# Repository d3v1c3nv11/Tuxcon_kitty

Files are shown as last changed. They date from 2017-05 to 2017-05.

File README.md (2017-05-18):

# DIY: Tuxcon_kitty

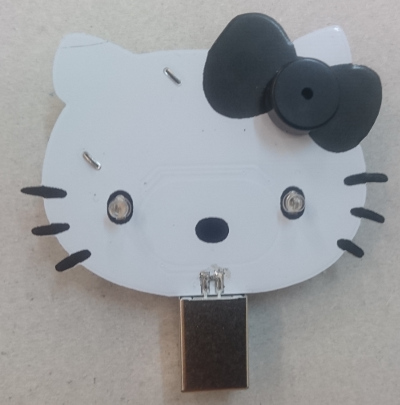
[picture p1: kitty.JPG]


Olimex's Tuxcon kitty

Arduino sketch file: https://github.com/d3v1c3nv11/Tuxcon_kitty/tree/master/hello_kitty

Hardware: https://github.com/d3v1c3nv11/Tuxcon_kitty/tree/master/Tuxcon_Kitty_hardware

Schematic in pdf format: https://github.com/d3v1c3nv11/Tuxcon_kitty/blob/master/tuxcon_kitty.pdf

################## IMPORTANT NOTE ##################

 Tuxcon Kitty board is preprogramed with modified micronucleus-t85 bootloader. You can download from here: https://github.com/d3v1c3nv11/micronucleus-t85

################## ENJOY! ##################

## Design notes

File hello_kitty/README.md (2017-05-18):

To upload the Arduino sketch file, you must:

################## Add the Attiny85 board support in Arduino ##################

1. Launch Arduino.
2. Go to:  File->Preferences
3. In the field "Additional Boards Managers URLs", add these links:
http://digistump.com/package_digistump_index.json
https://raw.githubusercontent.com/damellis/attiny/ide-1.6.x-boards-manager/package_damellis_attiny_index.json
4. Click "OK" to save changes

################## Add Micronucleus Programmer to Arduino IDE ##################

Please visit this web page to see how to add Micronucleus support to Arduino IDE
http://www.instructables.com/id/Adding-Digispark-with-bootloader-support-to-existi/

################## BEFOR UPLOADING THE SKETCH ##################

In order to compile and upload this program, you must have installed "Capacitive Sensor" library.
You can download it from:
http://playground.arduino.cc/Main/CapacitiveSensor?from=Main.CapSense

################## Compile and Download ##################

Before Compilation and Upload, you MUST UNPLUG your USB cable from this board.
Then you must choose the right board. To do so:

1. Go to  "Tools" menu and then to "Board:" submenu.
2. Scroll down until you find "Digispark (8mhz - No USB) "
3. Select that board.
4. Click Upload
5. In the black box in Arduino IDE (the output of Compiling/Uploading) you will see message like:
" Running Digispark Uploader...
  Plug in device now... (will timeout in 60 seconds) "
5. Plug-in the USB cable to the board.
6. Then you should see message in the same box, that says the Uploading is completed.

################## IMPORTANT NOTE ##################

This sketchfile is written to work with external DC supply (CR2032 battery), so if you want to 
power your Kitty board with USB, instead of battery, you should change this line from the sketch file:

 if (capacitance > 8)
Should be changed to:

 if (capacitance > 30) // If that value is incorrect, try changing it with different values, untill you manage to
start the Kitty singing by touching it's nose.

################## ENJOY! ##################

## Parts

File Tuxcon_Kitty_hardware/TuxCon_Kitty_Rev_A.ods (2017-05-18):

Designation | Quantity | Designator | Package
BADGE-PIN-CLIPS | 1
СЪЕДИНИТЕЛ USB-SDWH-4B-LF (USB-B ПРАВ) | 1 | USB1 | USB-B-EDGE
SMD ИС ATTINY85-20SU | 1 | U1 | SO-8_208mil
LED 3mm PTH BLUE | 2 | LED2,LED1 | LED-3mm-PTH-KA
БАТЕРИЯ Li 3 V 220 mAh CR2032-V | 1 | BAT1 | CR2032H
CR2032H_PTH | 1 | BAT1 | CR2032H_PTH
BUZZER PT1240P 20Vpp 4kHz 13.8MM | 1 | BUZ1 | BUZZER-PT1240
SMD КОНД 1206 12 PF C0G 50VDC 5% | 1 | C1 | C_1206_5MIL_DWS
SMD КОНД 1206 1 UF Y5V 50VDC 20% | 1 | C2 | C_1206_5MIL_DWS
SMD ДИОД MINIMELF LL1N4148 | 2 | D2,D3 | SOD80C-4148-KA
SMD ДИОД 1N5819 (S4) SOD-123 | 1 | D1 | SOD80C-4148-KA
SMD РЕЗ 1206 1 K 5% | 2 | R1,R2 | R_1206_5MIL_DWS
SMD РЕЗ 1206 1 M 5% | 2 | R3,R4 | R_1206_5MIL_DWS
SMD РЕЗ 1206 10 K 5% | 1 | R5 | R_1206_5MIL_DWS
SMD РЕЗ 1206 22 OHM 5% | 2 | R6,R7 | R_1206_5MIL_DWS
SMD РЕЗ 0805 1.5 K 5% | 1 | R8 | R_0805_5MIL_DWS
BATTERY CR2032H | 1
ГПП – Tuxcon Kitty_Rev.A | 1

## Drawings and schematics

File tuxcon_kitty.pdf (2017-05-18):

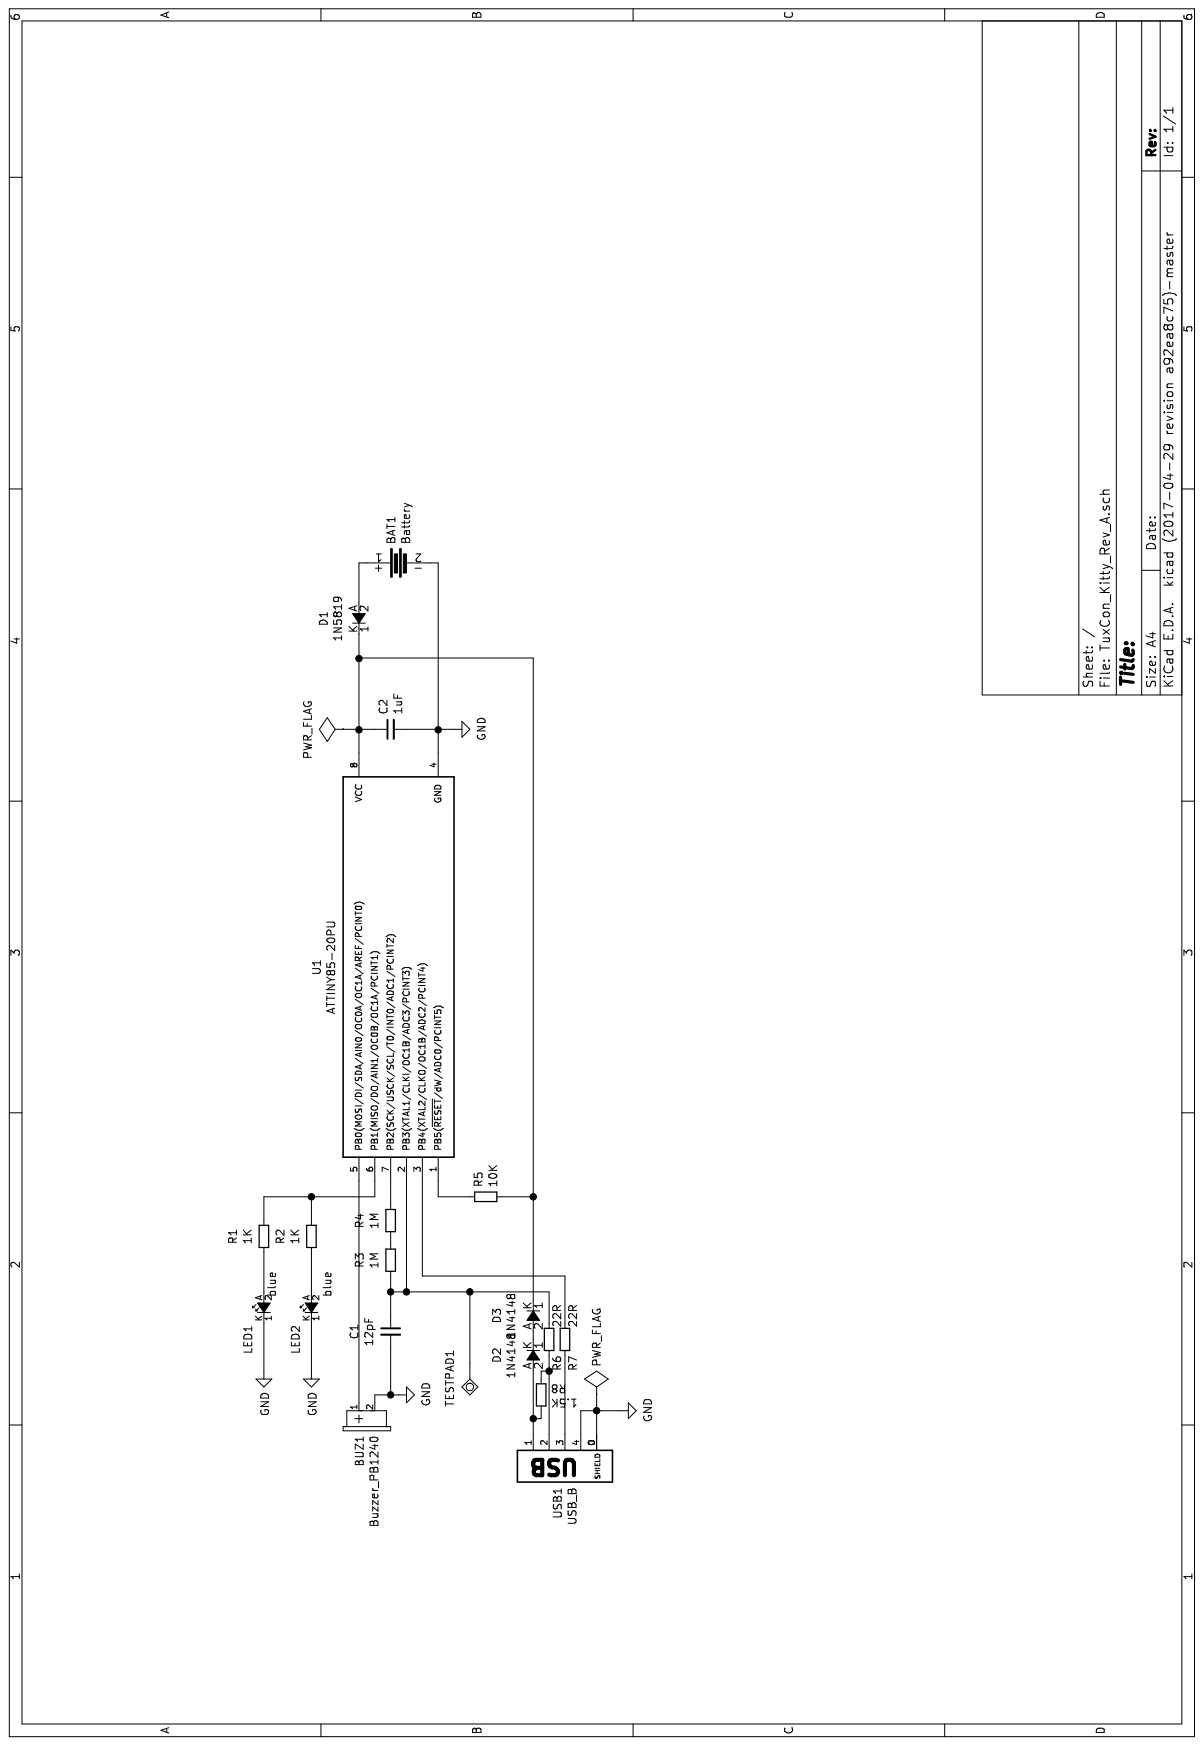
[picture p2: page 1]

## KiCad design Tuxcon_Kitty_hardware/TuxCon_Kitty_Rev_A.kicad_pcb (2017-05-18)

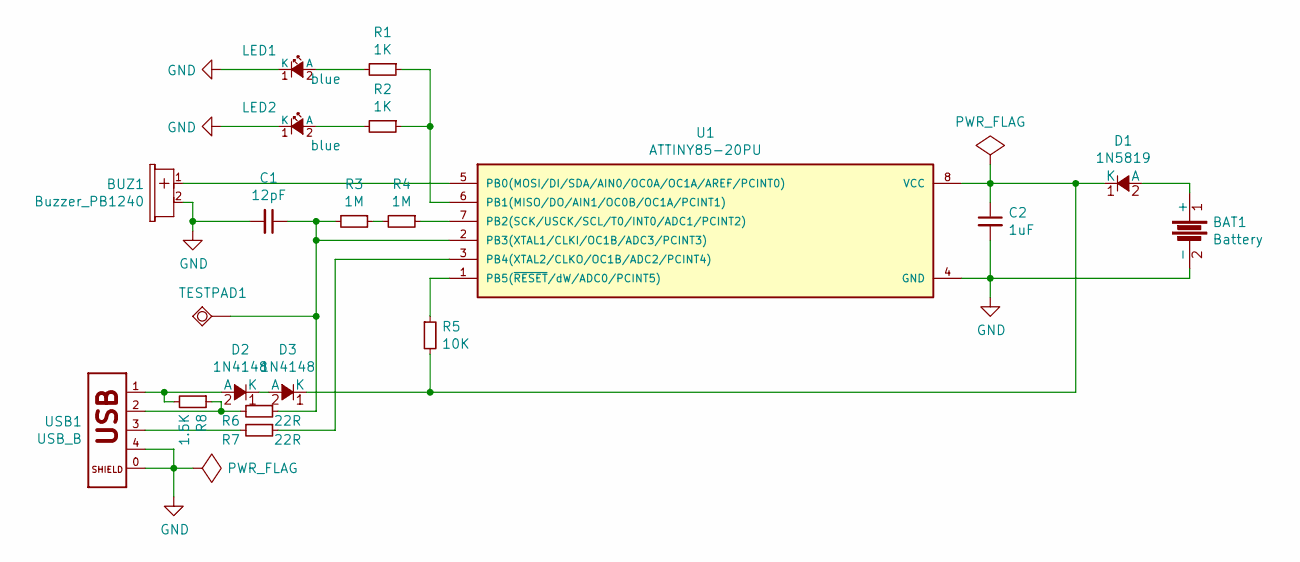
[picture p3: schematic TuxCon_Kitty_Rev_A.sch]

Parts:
BAT1: Battery; CR2032H_PTH
BUZ1: Buzzer_PB1240; BUZZER-PB1240
C1: 12pF; C_1206_5MIL_DWS
C2: 1uF; C_1206_5MIL_DWS
D1: 1N5819; SOD80C-4148-KA
D2, D3: 1N4148; SOD80C-4148-KA
LED1, LED2: blue; LED-3mm-PTH-KA
R1, R2: 1K; R_1206_5MIL_DWS
R3, R4: 1M; R_1206_5MIL_DWS
R5: 10K; R_1206_5MIL_DWS
R6, R7: 22R; R_1206_5MIL_DWS
R8: 1.5K; R_1206_5MIL_DWS
TESTPAD1: TESTPAD; TP_SMD_10.00x8.00mm
U1: ATTINY85-20PU; SOIC-8
USB1: USB_B; USB_Mini-B

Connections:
GND: BAT1.2 (-), BUZ1.2 (MINUS), C1.2, C2.2, LED1.1 (K), LED2.1 (K), U1.4 (GND), USB1.0 (5), USB1.4
unnamed: BAT1.1 (+), D1.2 (A)
unnamed: BUZ1.1 (PLUS), U1.5 (PB0(MOSI/DI/SDA/AIN0/OC0A/OC1A/AREF/PCI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)
unnamed: C1.1, R3.2, R6.1, TESTPAD1.1, U1.2 (PB3(XTAL1/CLKI/OC1B/ADC3/PCINT3))
unnamed: C2.1, D1.1 (K), D3.1 (K), R5.2, U1.8 (VCC)
unnamed: D2.1 (K), D3.2 (A)
unnamed: D2.2 (A), R8.2, USB1.1
unnamed: LED1.2 (A), R1.2
unnamed: LED2.2 (A), R2.2
unnamed: R1.1, R2.1, U1.6 (PB1(MISO/DO/AIN1/OC0B/OC1A/PCINT1))
unnamed: R3.1, R4.2
unnamed: R4.1, U1.7 (PB2(SCK/USCK/SCL/T0/INT0/ADC1/PCINT2))
unnamed: R5.1, U1.1 (PB5(~RESET~/dW/ADC0/PCINT5))
unnamed: R6.2, R8.1, USB1.2
unnamed: R7.1, U1.3 (PB4(XTAL2/CLKO/OC1B/ADC2/PCINT4))
unnamed: R7.2, USB1.3

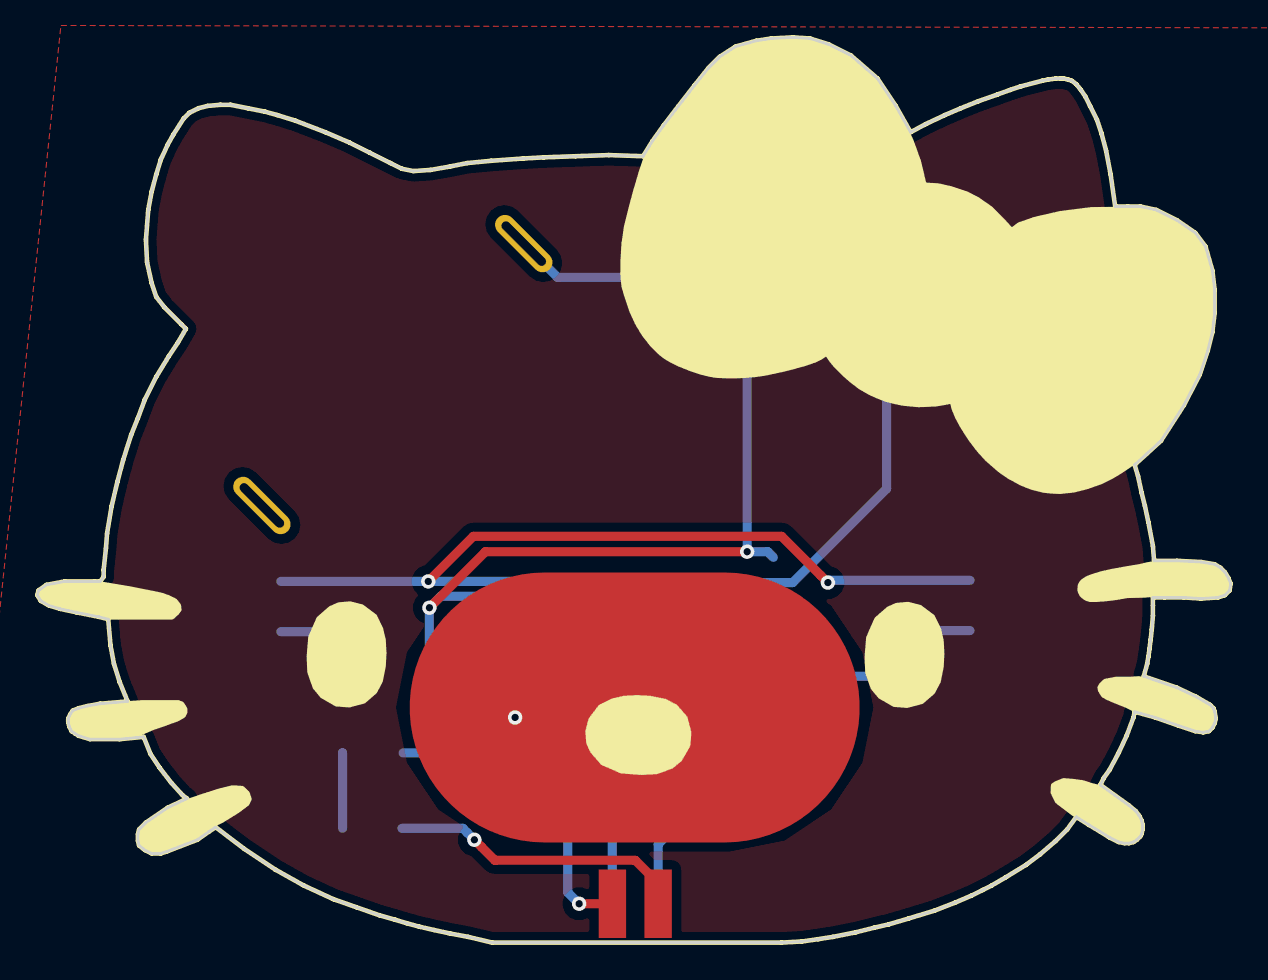
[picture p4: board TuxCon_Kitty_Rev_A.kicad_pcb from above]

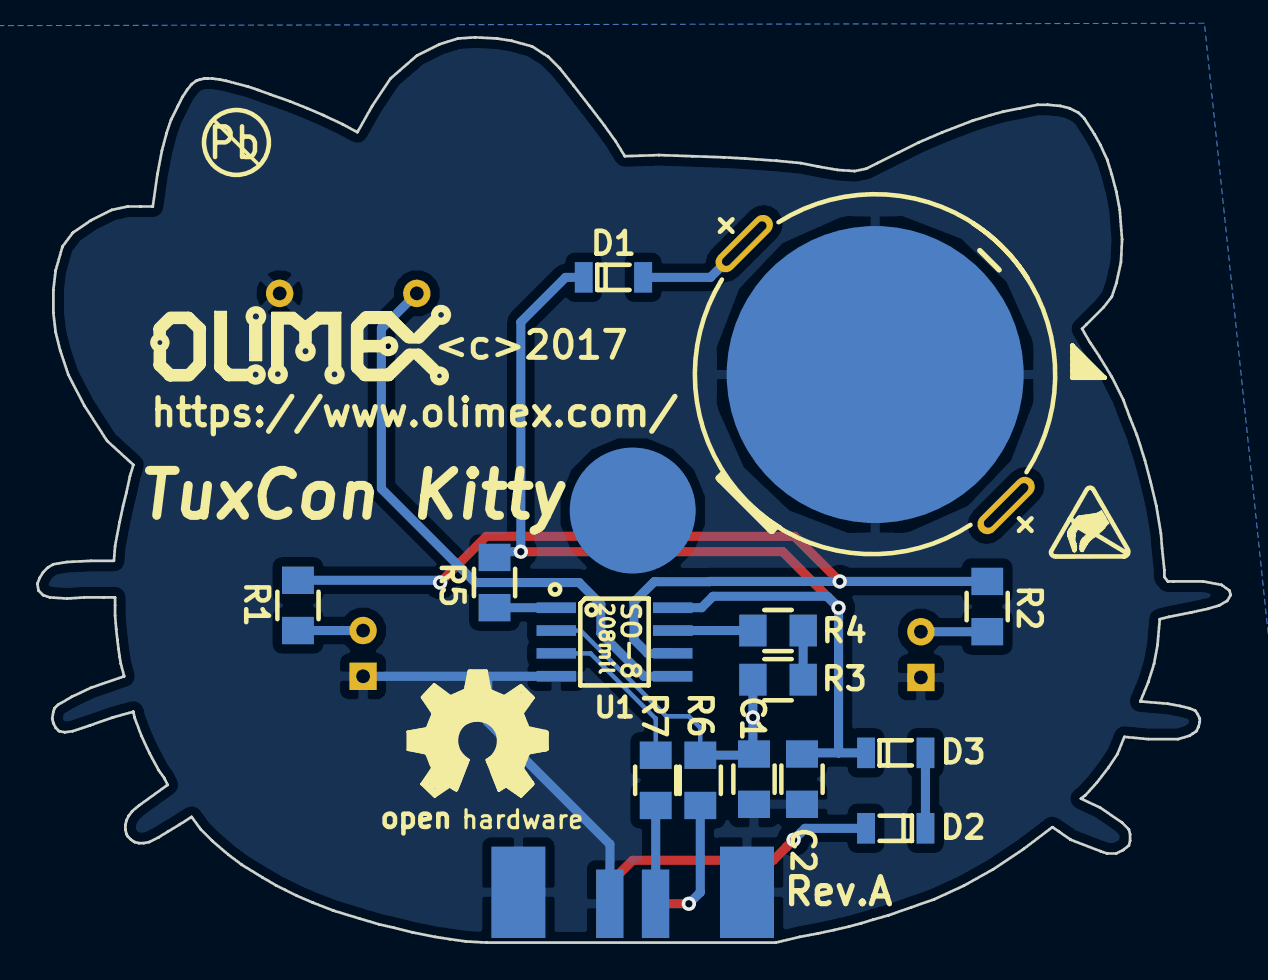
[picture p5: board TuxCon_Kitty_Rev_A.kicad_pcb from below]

Board: 2 copper layers, 66.3 x 50.3 mm, 21 parts (16 on the bottom side), 16 nets.

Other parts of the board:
Ref**: Val**; LOGO_ANTISTATIC_SMALL_4.5mmX2.8mm
TESTPAD1#2: TESTPAD; TP_SMD_10.00x8.00mm

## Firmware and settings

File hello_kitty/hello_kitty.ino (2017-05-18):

#include <avr/pgmspace.h>
#include <avr/io.h>
#include <avr/wdt.h>
#include <avr/sleep.h>
#include <avr/interrupt.h>
#include <CapacitiveSensor.h>
#include "definedtones.h"

//DefinePinNumebers:
int buzzer = 0;
int led = 1;
int chrge = 2;
int dischrge = 3;

CapacitiveSensor cs_2_3 = CapacitiveSensor(2, 3);


const int song[] PROGMEM = {
  G3,
  A3,
  DS3,
  E3,
  D3,
  DS3,
  D3,
  C3,
  C3,
  D3,
  DS3,
  DS3,
  D3,
  C3,
  D3,
  E3,
  G3,
  A3,
  E3,
  G3,
  D3,
  E3,
  C3,
  D3,
  C3,
  E3,
  G3,
  A3,
  E3,
  G3,
  C3,
  D3,
  C3,
  DS3,
  E3,
  DS3,
  D3,
  C3,
  D3,
  DS3,
  DS3,
  D3,
  C3,
  D3,
  E3,
  G3,
  D3,
  C3,
  D3,
  C3,
  C3,
  C3,
  G2,
  A2,
  C3,
  G2,
  A2,
  C3,
  E3,
  F3,
  E3,
  F3,
  E3,
  F3,
  G3,
  C3,
  C3,
  G2,
  A2,
  C3,
  E3,
  F3,
  E3,
  F3,
  G3,
  C3,
  B2,
  C3,
  G2,
  A2,
  C3,
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
};
const int duration[] PROGMEM = {
  QTH,
  QTH,
  ETH,
  QTH,
  ETH,
  ETH,
  ETH,
  QTH,
  QTH,
  QTH,
  QTH,
  ETH,
  ETH,
  ETH,
  ETH,
  ETH,
  ETH,
  ETH,
  ETH,
  ETH,
  ETH,
  ETH,
  ETH,
  ETH,
  ETH,
  QTH,
  QTH,
  ETH,
  ETH,
  ETH,
  ETH,
  ETH,
  ETH,
  ETH,
  ETH,
  ETH,
  ETH,
  ETH,
  ETH,
  QTH,
  ETH,
  ETH,
  ETH,
  ETH,
  ETH,
  ETH,
  ETH,
  ETH,
  QTH,
  QTH,
  QTH,
  QTH,
  ETH,
  ETH,
  QTH,
  ETH,
  ETH,
  ETH,
  ETH,
  ETH,
  ETH,
  ETH,
  ETH,
  ETH,
  ETH,
  QTH,
  QTH,
  ETH,
  ETH,
  ETH,
  ETH,
  ETH,
  ETH,
  ETH,
  ETH,
  QTH,
  QTH,
  QTH,
  ETH,
  ETH,
  QTH,
  ETH,
  ETH,
  ETH,
  ETH,
  ETH,
  ETH,
  ETH,
  ETH,
  ETH,
  ETH,
  QTH,
  QTH,
  ETH,
  ETH,
  ETH,
  ETH,
  ETH,
  ETH,
  QTH,
  HTH,

};

void setup_watchdog(int timerPrescaler) {

  if (timerPrescaler > 9 ) timerPrescaler = 9; //Correct incoming amount if need be

  byte bb = timerPrescaler & 7;
  if (timerPrescaler > 7) bb |= (1 << 5); //Set the special 5th bit if necessary

  //This order of commands is important and cannot be combined
  MCUSR &= ~(1 << WDRF); //Clear the watch dog reset
  WDTCR |= (1 << WDCE) | (1 << WDE); //Set WD_change enable, set WD enable
  WDTCR = bb; //Set new watchdog timeout value
  WDTCR |= _BV(WDIE); //Set the interrupt enable, this will keep unit from resetting after each int
}

ISR(WDT_vect) {

}

void enterSleep(void)
{
  set_sleep_mode(SLEEP_MODE_PWR_DOWN);   /* EDIT: could also use SLEEP_MODE_PWR_DOWN for lowest power consumption. */
  sleep_enable();

  /* Now enter sleep mode. */
  sleep_mode();

  /* The program will continue from here after the WDT timeout*/
  sleep_disable(); /* First thing to do is disable sleep. */

  /* Re-enable the peripherals. */
  // power_all_enable();
}

void setup() {

  pinMode(led, OUTPUT);
  digitalWrite(led, LOW);
  pinMode(buzzer, OUTPUT);
  digitalWrite(buzzer, LOW);


  cs_2_3.set_CS_AutocaL_Millis(0xFFFFFFFF);
  //Serial.begin(115200);

  set_sleep_mode(SLEEP_MODE_PWR_DOWN);
  sleep_enable();
  ADCSRA &= ~(1 << ADEN); //Disable ADC, saves ~230uA
  setup_watchdog(7); //Wake up after 2s.
}



void loop() {
  int cnote = 0;
  int cdur = 0;
  int ddelay = 0;
  bool ledon = 0;

  long i = 0;
  int temp = 0;

  long capacitance = 0;

  /*
  pinMode(2, OUTPUT);
  pinMode(3, INPUT);
  digitalWrite(2, LOW);
  while (digitalRead(3));

  pinMode(3, OUTPUT);
  pinMode(2, INPUT);
  digitalWrite(3, HIGH);
  while (!digitalRead(2)) i++;
  */

  
  //i = mycap.capacitiveSensor(30);


  //digitalWrite(1,HIGH);
  capacitance = cs_2_3.capacitiveSensor(30);

  if (capacitance > 8)
  {
    //for(int cnt=0;cnt<133;cnt++)
    for (int cnt = 0; cnt < 101; cnt++)
    {
      if (!ledon)  {
        digitalWrite(led, LOW);
        ledon = 1;
      }
      else
      {
        digitalWrite(led, HIGH);
        ledon = 0;
      }
      cnote = pgm_read_word_near(song + cnt); //notetobeplayed
      cdur = pgm_read_word_near(duration + cnt); //durationofthecurrentnote
      if (cnote > 0)
      {
        tone(buzzer, cnote);
        delay(cdur);
        noTone(buzzer);
        delay(3);

      }
      else {
        noTone(buzzer);
        delay(cdur);
      }

    }

  }
  wdt_reset();
  enterSleep();
}
